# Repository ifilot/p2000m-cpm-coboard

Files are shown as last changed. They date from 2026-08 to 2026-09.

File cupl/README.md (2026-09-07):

# ATF1502AS CUPL source

This directory contains the first CPLD implementation for the
`pcb/modern-revised` schematic. It targets an ATF1502AS in a PLCC-44 socket
with JTAG left enabled.

## Implemented behavior

- Reset selects the normal factory P2000 memory map. In this mode P0-P7
  reproduce the original 82S123 table independently of `/MRQ`, and local
  SRAM stays disabled.
- A normal Z80 I/O write to `0x20-0x2F` latches D7 as the CP/M-map enable.
- The CP/M map is:

| CPU range | Selected target |
|---|---|
| `0x0000-0x3FFF` | Motherboard RAM (`P1/RAMS1`) |
| `0x4000-0x9FFF` | Expansion RAM (`P7/RAMS2`) |
| `0xA000-0xDFFF` | Local 16 KiB SRAM (`/RAMS3`) |
| `0xE000-0xEFFF` | Second 4 KiB cartridge slice (`P5/CARS1`) |
| `0xF000-0xFFFF` | Video window through translated expansion address `0x5xxx` |

- In CP/M mode, `RA15..RA12` is `A15..A12 + 6` modulo 16. In normal mode,
  the address passes through unchanged.
- J3/pin 44 is low for the P2000M and high for the P2000T. The T model also
  asserts `/VIDS` for `0xF000-0xF7FF`, matching its 2 KiB physical video RAM.
- In CP/M mode, `/MRQ` gates every memory selection. Local `/RAMS3` always
  requires both CP/M mode and an active memory cycle, so I/O cycles cannot
  enable the local SRAM.

The fixed pin assignment is in `p2000m-cpm-coboard.pld`. Any schematic pin
change must be reflected there and in `verify.py`.

## Separate stock-only diagnostic image

`p2000m-stock-prom.pld` is a combinational replacement for the original
`literature/82s123_dump_mobo.bin` PROM table. It has no mode register, port
decoder, reset dependency, or `/MRQ` gating. Local `/RAMS3` is permanently high.
RA12-RA15 always equal A12-A15; A0-A11 pass directly through the PCB from J1 to
J2, so the expansion/video board receives the original CPU address.

Build and verify it separately:

```bat
cupl\build.bat stock
```

```sh
./cupl/build.sh stock
python3 cupl/verify.py --stock
```

Program `p2000m-stock-prom.jed` for this test. The fit uses 13/32 logic cells,
zero flip-flops, and leaves JTAG enabled. Its build does not overwrite the
CP/M-capable image. This reproduces the PROM's logical table; propagation
delays and physical board connections still require a hardware test.

For a controlled output-slew comparison, `p2000m-stock-fast.pld` contains the
same stock logic, fitted with `-str output_fast ON`. Build with `build.bat stock-fast`
or `./cupl/build.sh stock-fast`; program `p2000m-stock-fast.jed`. Verify with
`python3 cupl/verify.py --stock --source cupl/p2000m-stock-fast.pld`.
Fast slew changes output transitions, not the chip's physical speed grade;
it may improve timing margin or worsen ringing depending on the wiring.

## Windows build

Install WinCUPL II and run:

```bat
cupl\build.bat
```

The scripts expect WinCUPL in `C:\WINCUPL`. Override that location when
needed:

```bat
set CUPL_ROOT=C:\path\to\WINCUPL
cupl\build.bat
```

## Linux build with Wine

Install WinCUPL into a Wine prefix and run:

```sh
./cupl/build.sh
```

By default the script uses `${WINEPREFIX:-$HOME/.wine}/drive_c/WINCUPL`.
An alternative installation can be selected with:

```sh
CUPL_ROOT=/path/to/WINCUPL ./cupl/build.sh
```

Both build wrappers perform the same two proprietary steps:

1. `cupl.exe` compiles the CUPL source to a `.tt2` netlist.
2. `find1502.exe` fits that netlist for `P1502C44` and emits the `.jed` file.

The fitter is invoked with `JTAG ON`. Review the generated `.fit` and `.pin`
reports before programming hardware.

## Verification

The behavioral checker requires only Python 3:

```sh
python3 cupl/verify.py
python3 cupl/verify.py --dump
```

It parses and evaluates the actual `.pld` equations against independent expected
memory tables. Checks cover source pins and device, all 256 combinations of
2 KiB block/map/model/memory-request level, all sixteen address translations,
and 16,384 port/control/data/reset/prior-state combinations. Register checks
cover rising-edge capture, holding without an edge, asynchronous reset priority,
and complete write/reset sequences. `--dump` prints source-evaluated results.
Unsupported syntax, undefined signals, duplicate declarations, and combinational
feedback fail verification. Checks remain enabled under `python3 -O`.
Dependencies on inputs outside the corresponding truth-table sweep also fail,
so a newly introduced input cannot silently escape verification.

Run the checker regression tests, including deliberately broken CUPL equations:

```sh
python3 -m unittest discover -s cupl -p 'test_*.py'
```

This is functional source verification for the scalar CUPL syntax used here.
It does not verify JEDEC fuses, propagation delays, setup/hold timing, or physical
hardware. A fresh compiler/fitter run and review of its reports are still required.
The existing ATF1502AS fitter report uses 14 of 32 logic cells, with JTAG enabled.

Generated compiler and fitter files are ignored. Clean them with
`cupl\clean.bat` or `./cupl/clean.sh`.

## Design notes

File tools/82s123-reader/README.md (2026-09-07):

# 82S123 ROM Reader

Hardware and software to read out 82S123 bipolar PROM chips using an
[Arduino Leonardo](https://docs.arduino.cc/hardware/leonardo)-based shield,
plus a Qt6 desktop GUI to drive it.

The repository is organized as follows:

* [arduino/82s123-reader](arduino/82s123-reader) — firmware for the Leonardo.
  It exposes a small serial command protocol (handshake + checksummed read)
  so a host application can request a dump on demand, rather than the board
  dumping blindly on boot.
* [gui](gui) — a Qt6 Widgets desktop application that connects to the board,
  reads the 32 bytes of the chip, displays them (hex / decimal / binary /
  ASCII), and exports the dump as `.bin`, Intel `.hex`, or a text table. See
  [gui/README.md](gui/README.md) for build and usage instructions.
* [kicad/82s123-reader](kicad/82s123-reader) — KiCad project for the reader
  shield.

## Wiring

| Signal | Arduino pin |
|---|---|
| ROM A0–A4 | D2, D3, D4, D5, D6 |
| ROM /CE | D7 |
| ROM D0–D3 | A3–A0 (PF4–PF7) |
| ROM D4–D7 | D8–D11 (PB4–PB7) |

## Firmware protocol

115200 baud, 8N1, ASCII, newline-terminated commands/responses:

| Host sends | Device replies |
|---|---|
| `PING` | `PONG 82S123-READER v0.1.0` |
| `READ` | 32× `AA:DD` lines (address:data, hex), then `CHK:xx` (XOR checksum of all 32 data bytes), then `OK` |
| anything else | `ERR UNKNOWN_CMD <cmd>` |

The GUI (or any other host, e.g. a serial terminal) drives the board with
these commands; the board never dumps unsolicited data, which makes reads
deterministic and easy to verify (missing bytes or a checksum mismatch are
detected instead of silently producing a bad dump).

## Quick start

1. Flash [`arduino/82s123-reader/82s123-reader.ino`](arduino/82s123-reader/82s123-reader.ino)
   to the Leonardo via the Arduino IDE.
2. Build the GUI — see [gui/README.md](gui/README.md).
3. Insert the 82S123 chip, connect the board, launch the GUI, connect to its
   serial port, and click **Read ROM**.

## Example dump

A sample 32-byte read from a 82S123 chip, as reported by the reader:

```
Address | Data
--------+------
0x00    | 0x02
0x01    | 0x07
0x02    | 0x0B
0x03    | 0x0F
0x04    | 0x12
0x05    | 0x17
0x06    | 0x1B
0x07    | 0x1F
0x08    | 0x22
0x09    | 0x27
0x0A    | 0x2A
0x0B    | 0x2F
0x0C    | 0x32
0x0D    | 0x37
0x0E    | 0x39
0x0F    | 0x3F
0x10    | 0x02
0x11    | 0x07
0x12    | 0x0B
0x13    | 0x0F
0x14    | 0x12
0x15    | 0x17
0x16    | 0x1B
0x17    | 0x1F
0x18    | 0x22
0x19    | 0x27
0x1A    | 0x2A
0x1B    | 0x2F
0x1C    | 0x32
0x1D    | 0x37
0x1E    | 0x3B
0x1F    | 0x3F
```

Read twice in a row, the dump was consistent except for address `0x0E`,
which alternated between `0x39` and `0x3B` — a sign of a marginal/floating
bit on that ROM read at the time (loose socket contact or a chip near its
switching threshold), rather than a firmware issue. The GUI's per-read
checksum check will flag such inconsistencies if they cause a corrupted
transfer, but a genuinely flaky chip/socket read that completes cleanly on
both ends can still produce different (self-consistent) data — worth
re-seating the chip and re-reading if you see this.

## Licensing

* All source code, i.e. the [firmware](arduino/82s123-reader) and the
  [GUI](gui), is released under a
  [GPLv3 license](https://www.gnu.org/licenses/gpl-3.0.html).
* The hardware files to (re)produce the Arduino shield are released under
  the [CC BY-SA 4.0](https://creativecommons.org/licenses/by-sa/4.0/)
  license.

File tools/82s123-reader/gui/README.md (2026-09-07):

# 82S123 ROM Reader — Qt6 GUI

A minimal Qt6 Widgets front-end for the Arduino Leonardo based 82S123 PROM
reader. It talks to the board over a small, checksummed serial protocol
(see [Protocol](#protocol) below), reads all 32 bytes of the chip, shows
them in a table (hex / decimal / binary / ASCII), and exports the dump as
`.bin`, Intel `.hex`, or a plain-text table. It can also flash the board
with the exact firmware it was built against (see
[Flashing firmware](#flashing-firmware)).

The UI intentionally uses only stock Qt widgets and the platform's default
style — no custom stylesheets/CSS.

## Layout

```
gui/
  CMakeLists.txt
  src/
    main.cpp                entry point
    mainwindow.h/.cpp        Qt Widgets UI
    romreader.h/.cpp         QSerialPort-based protocol client
    firmwareflasher.h/.cpp   compiles/uploads the firmware via arduino-cli
    firmware_source.h.in     template into which the .ino is embedded
  resources/
    app.svg                  icon source
    app.ico                  Windows executable icon (generated from app.svg)
    icons/app-*.png          in-app icon (generated from app.svg)
    app.qrc                  Qt resource bundling the PNGs
    app.rc.in                Windows resource script embedding app.ico
```

The firmware sketch (`arduino/82s123-reader/82s123-reader.ino`) is embedded
into the binary at CMake configure time as a generated header
(`build/generated/firmware_source.h`), so the "Flash Firmware" feature
always uploads the exact sketch version the GUI was built against —
editing the `.ino` and reconfiguring picks up the change automatically.

The app icon is embedded twice, both generated from the single
`resources/app.svg` source (regenerate with `rsvg-convert` + ImageMagick's
`convert` if you edit the SVG — there's no build-time step for this, unlike
the firmware): as PNGs via `app.qrc` for the in-app window/taskbar icon, and
as `app.ico` baked into the `.exe`'s own PE resources on Windows (via a
generated `.rc` file), so it shows up in Explorer and the taskbar even
before the app runs.

## Building

Requires Qt6 (`Widgets` + `SerialPort` modules) and CMake ≥ 3.16.

### Windows via MSYS2 (UCRT64)

Install the needed packages once from an MSYS2 shell:

```
pacman -S mingw-w64-ucrt-x86_64-qt6-base mingw-w64-ucrt-x86_64-qt6-serialport \
          mingw-w64-ucrt-x86_64-cmake mingw-w64-ucrt-x86_64-ninja \
          mingw-w64-ucrt-x86_64-toolchain
```

Then, from a **UCRT64** MSYS2 shell (or any shell with `C:\msys64\ucrt64\bin`
on `PATH`):

```
cmake -G Ninja -S gui -B gui/build -DCMAKE_PREFIX_PATH=C:/msys64/ucrt64 -DCMAKE_BUILD_TYPE=Release
cmake --build gui/build
```

The resulting `prom82s123-reader.exe` dynamically links `Qt6Core`, `Qt6Gui`,
`Qt6Widgets`, `Qt6SerialPort`, plus the MinGW runtime
(`libgcc_s_seh-1.dll`, `libstdc++-6.dll`, `libwinpthread-1.dll`). To make the
build folder self-contained/redistributable:

```
cd gui/build
windeployqt6.exe prom82s123-reader.exe --no-translations --no-opengl-sw
cp C:/msys64/ucrt64/bin/{libgcc_s_seh-1,libstdc++-6,libwinpthread-1}.dll .
```

### Linux

```
sudo apt install qt6-base-dev qt6-serialport-dev cmake ninja-build
cmake -G Ninja -S gui -B gui/build
cmake --build gui/build
```

On Linux, add your user to the `dialout` group (or equivalent) to get
permission to open `/dev/ttyACM*`.

## Usage

1. Flash the firmware onto the Leonardo — either with the Arduino IDE, or
   with the GUI itself (see below).
2. Launch `prom82s123-reader`, pick the board's serial port, click **Connect**
   (the app performs a `PING`/`PONG` handshake and will report a clear error
   if the board doesn't answer).
3. Click **Read ROM** to pull all 32 bytes; the table fills in and the
   checksum is verified automatically.
4. **Save As…** to export as `.bin`, Intel `.hex`, or a text table.
5. **View → Show Log** for a raw transcript of the serial conversation,
   useful for troubleshooting.

## Flashing firmware

The **Flash Firmware…** button (also under the **Firmware** menu) compiles
and uploads the embedded sketch directly from the GUI, by shelling out to
[`arduino-cli`](https://arduino.github.io/arduino-cli/) — it does not bundle
its own AVR toolchain.

* On first use, the app searches `PATH` and a couple of well-known install
  locations for `arduino-cli`; if it can't find one, it prompts you to
  browse to the executable. The chosen path is remembered (`QSettings`) and
  can be changed any time via **Firmware → Locate arduino-cli…**.
* The `arduino:avr` core must be installed once: `arduino-cli core install
  arduino:avr`.
* Flashing closes any active connection to the board first (the port can't
  be shared between the GUI and the upload tool), asks for confirmation
  (it overwrites the board's firmware), then streams `arduino-cli`'s
  compile/upload output live into the log panel while an indeterminate
  progress dialog is shown (cancellable).
* Internally it writes the embedded sketch to a temporary directory and
  runs `arduino-cli compile --upload -p <port> --fqbn arduino:avr:leonardo
  <sketch>` — the same command you'd run by hand.

## Protocol

115200 baud, 8N1, ASCII, newline-terminated commands/responses:

| Host sends | Device replies |
|---|---|
| `PING` | `PONG 82S123-READER v0.1.0` |
| `READ` | 32× `AA:DD` lines (address:data, hex), then `CHK:xx` (XOR checksum of all data bytes), then `OK` |
| anything else | `ERR UNKNOWN_CMD <cmd>` |

The GUI treats the handshake and the read as timeout-guarded operations
(1.5 s / 3 s respectively) and validates that all 32 addresses were seen and
that the checksum matches before accepting a read, so a dropped byte or a
disconnected cable is reported instead of silently producing a bad dump.

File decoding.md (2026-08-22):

# P2000M CP/M memory-map audit

Sources checked:

- `literature/MW106 CPM Kaart.pdf`, especially page 3 (EPROM bytes) and page
  16 (SANECAL schematic).
- `literature/P2000MT Field Support Manual.pdf`, especially pages 3-3, 3-5,
  3-14, 3-18 and 3-19.
- `software/CPM Nater.bin`.
- The current KiCad schematic and routed PCB.

## Result

The authoritative CP/M map is:

| CPU range | Effective device |
|---|---|
| `0x0000-0x3FFF` | 16 KiB motherboard RAM |
| `0x4000-0x9FFF` | 24 KiB expansion-card RAM |
| `0xA000-0xDFFF` | 16 KiB local card RAM |
| `0xE000-0xEFFF` | Second 4 KiB cartridge-ROM slice |
| `0xF000-0xFFFF` | P2000M video RAM |

The monitor ROM is not mapped in CP/M mode. The machine-readable source of
truth is `P2000M_MEMORY_TABLE` in `scripts/build_eeprom.py`.

## Original maps

The stock functional map documented by Philips is:

| CPU range | Device |
|---|---|
| `0x0000-0x0FFF` | Monitor ROM |
| `0x1000-0x4FFF` | Cartridge ROM |
| `0x5000-0x5FFF` | P2000M video RAM |
| `0x6000-0x9FFF` | 16 KiB motherboard RAM |
| `0xA000-0xFFFF` | Up to 24 KiB expansion RAM |

MW106 page 3 prints these 32 bytes for its M-model CP/M table:

```text
7E 7E 7E 7E  FE FE FE FE  7D 7D 7D 7D  7D 7D 7D 7D
FD FD FD FD  F9 F9 F9 F9  F9 F9 F9 F9  DC DC FD FD
```

One byte covers a 2 KiB CPU page. Together with the SANECAL local RAM and its
address adder, the effective M-model CP/M map is:

| CPU range | MW106 byte | Effective device |
|---|---:|---|
| `0x0000-0x1FFF` | `0x7E` | Motherboard RAM |
| `0x2000-0x3FFF` | `0xFE` | Motherboard RAM (with the literal extra `RAMS2` output) |
| `0x4000-0x7FFF` | `0x7D` | SANECAL local 16 KiB RAM; all external selects are off |
| `0x8000-0x9FFF` | `0xFD` | Expansion RAM |
| `0xA000-0xDFFF` | `0xF9` | Expansion RAM |
| `0xE000-0xEFFF` | `0xDC` | CP/M cartridge boot ROM |
| `0xF000-0xFFFF` | `0xFD` | P2000M video RAM |

## Revised-board decode

### U2 address inputs

| U2 input | Source |
|---|---|
| A0-A4 | CPU A11-A15 |
| A5 | J3: M=`0`, T=`1` |
| A6 | `/MRQ` |
| A7-A16 | GND |

Therefore:

```text
U2 address = (CPU address >> 11) | (T_model << 5) | (/MRQ_level << 6)
```

The additional `/MRQ` input is handled correctly. Memory cycles use U2
addresses `0x00-0x3F`. I/O and idle cycles use `0x40-0x7F`, which must contain
`0x7D` throughout so U1 cannot be selected while `/RD` or `/WR` is active for
I/O.

### U2 outputs as actually routed

| Bit | Net | Active level |
|---:|---|---:|
| D0 | P0 `/MBEN` | 0 |
| D1 | P1 `RAMS1` | 1 |
| D2 | `/RAMS3` (U1 `/CS`) | 0 |
| D3 | P2 `/VIDS` | 0 |
| D4 | Not connected | - |
| D5 | P5 `/CARS1` | 0 |
| D6 | P6 `/CARS2` | 0 |
| D7 | P7 `RAMS2` | 1 |

P3 `/ROMS1` and P4 `/ROMS2` are held inactive by R2 and R1. Because D4 is not
connected, an EEPROM option that tries to select ROM2 through D4 cannot work on
this PCB.

### Authoritative P2000M CP/M table

| CPU range | U2 byte | Effective device |
|---|---:|---|
| `0x0000-0x3FFF` | `0x7E` | 16 KiB motherboard RAM |
| `0x4000-0x9FFF` | `0xFD` | 24 KiB expansion-card RAM |
| `0xA000-0xDFFF` | `0x79` | 16 KiB U1 SRAM |
| `0xE000-0xEFFF` | `0x5C` | 4 KiB CP/M cartridge boot-ROM slice |
| `0xF000-0xFFFF` | `0xFD` | P2000M video RAM |

U1 uses CPU A0-A13 directly and has A14 grounded. Its four physical 4 KiB
blocks appear linearly from `0x0000` through `0x3FFF` within the logical
`0xA000-0xDFFF` window. Every SRAM byte is mapped exactly once.

The CP/M boot ROM contains `LD A,0x80` at file offset `0x036D` and
`OUT (0x20),A` at `0x0372`. U5 correctly decodes the mirrored write-port range `0x20-0x2F`, and
U4 therefore must (and does) latch D7, despite the D0 annotation in the MW106
drawing.

## EEPROM image

The concise generator is `scripts/build_eeprom.py`:

```sh
python3 scripts/build_eeprom.py p2000m-cpm-eeprom.bin
```

It writes a complete 128 KiB SST39SF010 image. Bytes `0x00-0x3F` are the M/T
memory-cycle tables, bytes `0x40-0x7F` are the `/MRQ=1` all-off tables, and the
unaddressed remainder is erased (`0xFF`).

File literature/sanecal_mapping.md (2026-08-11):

# SANECAL MW106 M-model mapping

PROM encoding as printed in MW106:

```text
00  7E 7E 7E 7E  FE FE FE FE  7D 7D 7D 7D  7D 7D 7D 7D
10  FD FD FD FD  F9 F9 F9 F9  F9 F9 F9 F9  DC DC FD FD
```

Several printed values cannot form a valid decode with the signal assignments
on this board. `FE` asserts both active-high RAM selects, `7D` selects no
memory, `F9` asserts both `RAMS2` and `RAMS3/`, and `DC` asserts both `RAMS2`
and `CARS1/`. They are treated here as errors in the printed MW106 table. The
corrected functional encoding keeps the memory selects mutually exclusive:

```text
00  7E 7E 7E 7E  7E 7E 7E 7E  FD FD FD FD  FD FD FD FD
10  FD FD FD FD  79 79 79 79  79 79 79 79  5C 5C FD FD
```

## Signal lines

| Line | Signal on this board | Active level | Function |
|---|---|---:|---|
| D0 | `MBEN/` | 0 | Enables the memory data-bus path |
| D1 | `RAMS1` | 1 | Selects the 16 KiB motherboard system RAM |
| D2 | `RAMS3/` | 0 | Selects the CP/M board's local RAM |
| D3 | `VIDS/` | 0 | Selects video RAM |
| D4 | Unconnected | - | No function on this board |
| D5 | `CARS1/` | 0 | Selects cartridge ROM bank 1 (`1000-2FFF`) |
| D6 | `CARS2/` | 0 | Selects cartridge ROM bank 2 (`3000-4FFF`) |
| D7 | `RAMS2` | 1 | Selects the 24 KiB expansion RAM |
| P3 | `ROMS1/` | 0 | Selects the lower 2 KiB monitor ROM; held at 1 (inactive) on this board |
| P4 | `ROMS2/` | 0 | Selects the upper 2 KiB monitor ROM; held at 1 (inactive) on this board |

## Interpretation

Each PROM address covers one 2 KiB CPU-address block because CPU address lines
A11-A15 drive the PROM address inputs. Consecutive blocks that contain the same
data are combined below; the block count states how many 2 KiB blocks the row
covers. `0` is low and `1` is high, and the slash in a signal name denotes an
active-low signal. D4 is included even though it is not connected. P3 and P4
are not driven by the PROM and remain high throughout.

The final column relates the CP/M-visible range to the corresponding part of
the stock P2000M map. `RAMS3/` has no equivalent destination in the stock map;
when asserted, it connects the CPU to the RAM fitted on the CP/M board.

| Data | Blocks | PROM addresses | CPU address range | D7 `RAMS2` | D6 `CARS2/` | D5 `CARS1/` | D4 unconnected | D3 `VIDS/` | D2 `RAMS3/` | D1 `RAMS1` | D0 `MBEN/` | P3 `ROMS1/` | P4 `ROMS2/` | Landing relative to the stock P2000M map |
|---:|---:|---:|---|---:|---:|---:|---:|---:|---:|---:|---:|---:|---:|---|
| `7E` | 8 | `00-07` | `0000-3FFF` | 0 | 1 | 1 | 1 | 1 | 1 | 1 | 0 | 1 | 1 | `6000-9FFF`: all 16 KiB of motherboard RAM |
| `FD` | 12 | `08-13` | `4000-9FFF` | 1 | 1 | 1 | 1 | 1 | 1 | 0 | 1 | 1 | 1 | `A000-FFFF`: all 24 KiB of expansion RAM |
| `79` | 8 | `14-1B` | `A000-DFFF` | 0 | 1 | 1 | 1 | 1 | 0 | 0 | 1 | 1 | 1 | `RAMS3/` connects to the 16 KiB RAM on the CP/M board; there is no stock-map equivalent |
| `5C` | 2 | `1C-1D` | `E000-EFFF` | 0 | 1 | 0 | 1 | 1 | 1 | 0 | 0 | 1 | 1 | Selects the `CARS1/` ROM slice originally visible at `2000-2FFF` |
| `FD` | 2 | `1E-1F` | `F000-FFFF` | 1 | 1 | 1 | 1 | 1 | 1 | 0 | 1 | 1 | 1 | `5000-5FFF`: M-model video RAM through the translated address and the video-board decoder |

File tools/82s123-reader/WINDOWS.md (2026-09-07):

# Windows reader control

Software copied from `D:\PROGRAMMING\KiCAD\82S123-reader`, commit
`a315694` (Arduino firmware, Qt GUI and original README; hardware and build
outputs excluded). Original licensing remains as described in README.md.

The local firmware identifies as `82S123-READER v0.1.1` to distinguish this
copy. Its reading logic includes the existing Leonardo JTAG-disable sequence.
The GUI binary-export bug is corrected here: `.bin` files use binary mode.

Use Windows PowerShell and the Windows Arduino CLI:

```powershell
.\tools\82s123-reader\windows.ps1 -Action Build
.\tools\82s123-reader\windows.ps1 -Action Ports
.\tools\82s123-reader\windows.ps1 -Action Flash -Port COM5
.\tools\82s123-reader\windows.ps1 -Action Read -Port COM5 -Reads 3
```

Replace COM5 with the actual Leonardo port. Close the GUI/Serial Monitor
before using this controller. `Build` does not upload anything. `Flash`
recompiles and uploads with verification; it requires an explicit port.
`Read` checks the firmware identity, captures three independent reads, checks
each transfer checksum, compares all reads, and compares against the existing
`literature/82s123_dump_mobo.bin`. It never overwrites that reference file.

Captures are written as exact binary bytes alongside a serial log in an
ignored, timestamped `captures` subdirectory. Repeated agreement and the
checksum do not prove that the electrical reading of the PROM is correct.

From WSL, invoke the script through `powershell.exe -NoProfile
-ExecutionPolicy Bypass -File` using its Windows path. Compilation, uploading
and serial access all run on Windows; no WSL USB forwarding is needed.

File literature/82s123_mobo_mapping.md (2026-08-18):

# 82S123 motherboard PROM — normal (factory) mapping

Source: `literature/82s123_dump_mobo.bin`, a 32-byte dump of the 82S123 PROM
fitted on the motherboard, before any CP/M-board modification.

PROM contents as dumped:

```text
00  74 74 5C 5C  5C 5C 3C 3C  3C 3C 79 7D  7E 7E 7E 7E
10  7E 7E 7E 7E  FD FD FD FD  FD FD FD FD  FD FD FD FD
```

This is a clean decode: every byte selects at most one device, and no output
combination is contradictory (unlike the printed MW106 CP/M table, see
[sanecal_mapping.md](sanecal_mapping.md)). It is byte-for-byte identical to
the "P2000M, 1×2732" table in `literature/address_decoding.txt`, which fixes
both the ROM configuration (one 4 KiB 2732, not two 2 KiB 2716s — bytes
`00-01` are both `74`, not `74`/`6C`) and the signal-to-bit wiring below. This
dump is also the empirical source for that table's `5000-5FFF` row, which was
previously an unverified guess (see the note below).

## Signal lines

| Line | Signal | Active level | Function |
|---|---|---:|---|
| D0 | `MBEN/` | 0 | Enables the memory data-bus path |
| D1 | `RAMS1` | 1 | Selects the 16 KiB motherboard system RAM |
| D2 | `VIDS/` | 0 | Selects video RAM |
| D3 | `ROMS1/` | 0 | Selects the monitor ROM (2732: whole 4 KiB device) |
| D4 | `ROMS2/` | 0 | Selects the upper monitor-ROM half (unused with a 2732; only relevant for the 2×2716 variant) |
| D5 | `CARS1/` | 0 | Selects cartridge ROM bank 1 (`1000-2FFF`) |
| D6 | `CARS2/` | 0 | Selects cartridge ROM bank 2 (`3000-4FFF`) |
| D7 | `RAMS2` | 1 | Selects the 24 KiB expansion RAM |

## Interpretation

Each PROM address covers one 2 KiB CPU-address block because CPU address lines
A11-A15 drive the PROM address inputs. Consecutive blocks that contain the
same data are combined below.

| Data | Blocks | PROM addresses | CPU address range | D7 `RAMS2` | D6 `CARS2/` | D5 `CARS1/` | D4 `ROMS2/` | D3 `ROMS1/` | D2 `VIDS/` | D1 `RAMS1` | D0 `MBEN/` | Function |
|---:|---:|---:|---|---:|---:|---:|---:|---:|---:|---:|---:|---|
| `74` | 2 | `00-01` | `0000-0FFF` | 0 | 1 | 1 | 1 | 0 | 1 | 0 | 0 | 4 KiB monitor ROM (single 2732) |
| `5C` | 4 | `02-05` | `1000-2FFF` | 0 | 1 | 0 | 1 | 1 | 1 | 0 | 0 | Cartridge ROM bank 1 |
| `3C` | 4 | `06-09` | `3000-4FFF` | 0 | 0 | 1 | 1 | 1 | 1 | 0 | 0 | Cartridge ROM bank 2 |
| `79` | 1 | `0A` | `5000-57FF` | 0 | 1 | 1 | 1 | 1 | 0 | 0 | 1 | Video RAM |
| `7D` | 1 | `0B` | `5800-5FFF` | 0 | 1 | 1 | 1 | 1 | 1 | 0 | 1 | Nothing selected (unused window) |
| `7E` | 8 | `0C-13` | `6000-9FFF` | 0 | 1 | 1 | 1 | 1 | 1 | 1 | 0 | 16 KiB motherboard RAM |
| `FD` | 12 | `14-1F` | `A000-FFFF` | 1 | 1 | 1 | 1 | 1 | 1 | 0 | 1 | 24 KiB expansion RAM |

## Note on M vs T

This chip was pulled from a known P2000M motherboard, so the `79`/`7D` split
at `5000-5FFF` (`VIDS/` asserted for `5000-57FF`, nothing selected for
`5800-5FFF`) is confirmed M-model data.

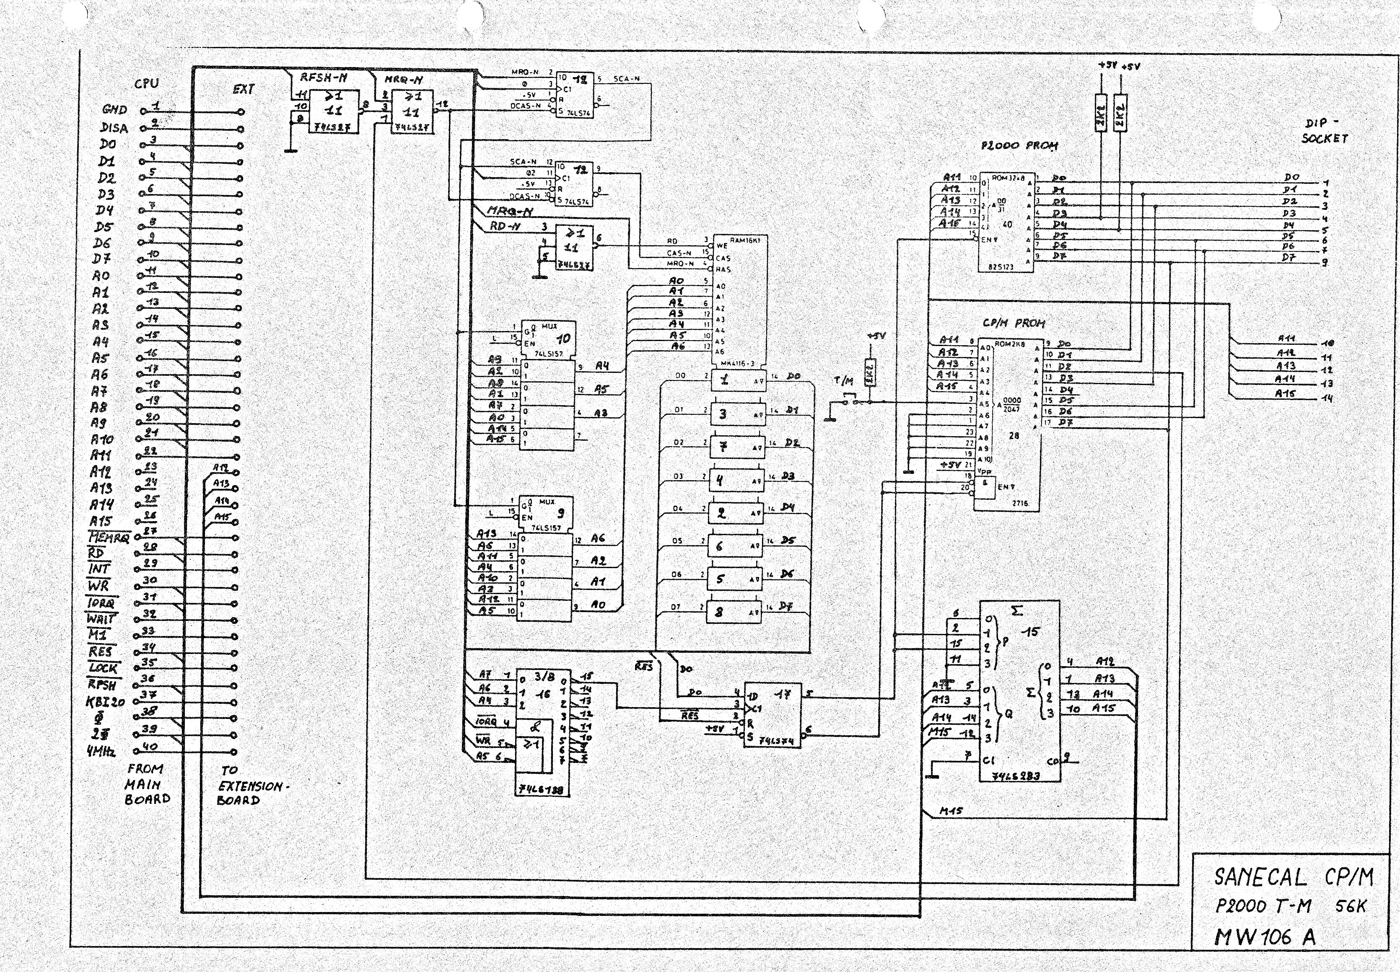
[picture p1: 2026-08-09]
literature/MW106-CPM-board-page16-restored-scan.png

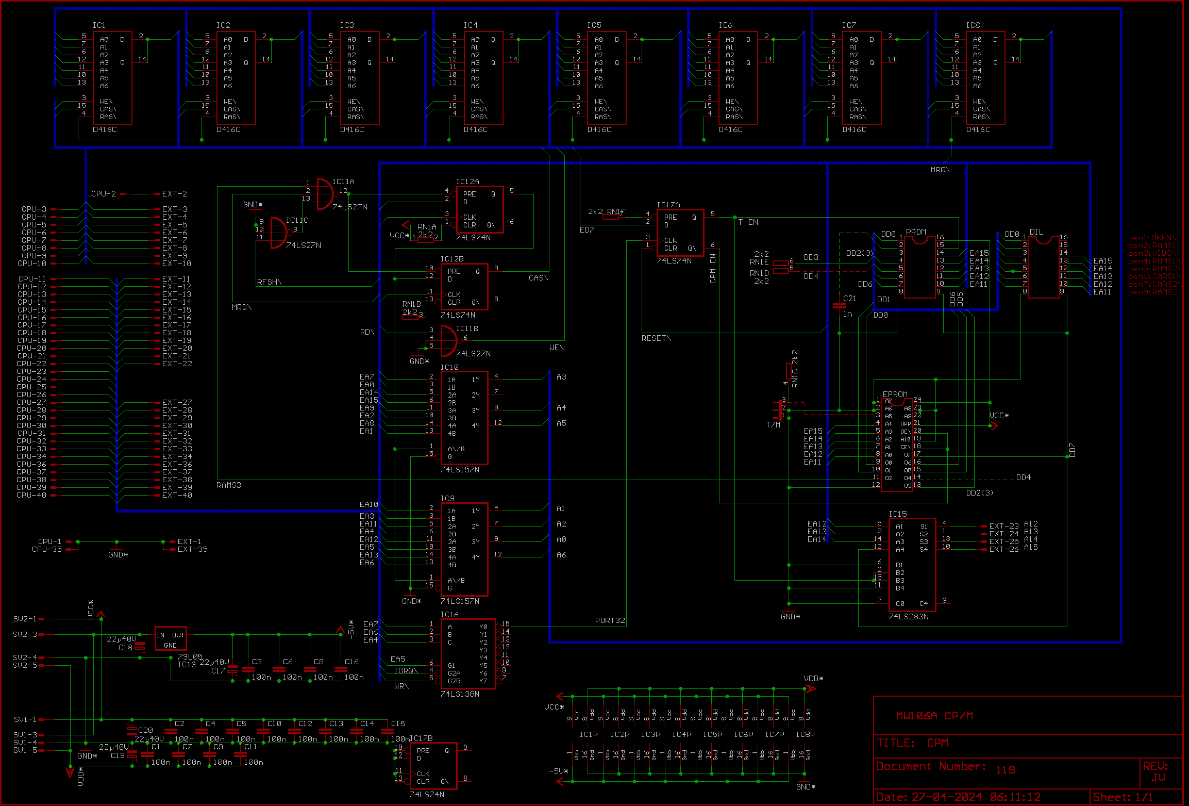
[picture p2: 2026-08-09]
literature/CPM.png.832bb497661575f88c8b2b641b03f00d.png

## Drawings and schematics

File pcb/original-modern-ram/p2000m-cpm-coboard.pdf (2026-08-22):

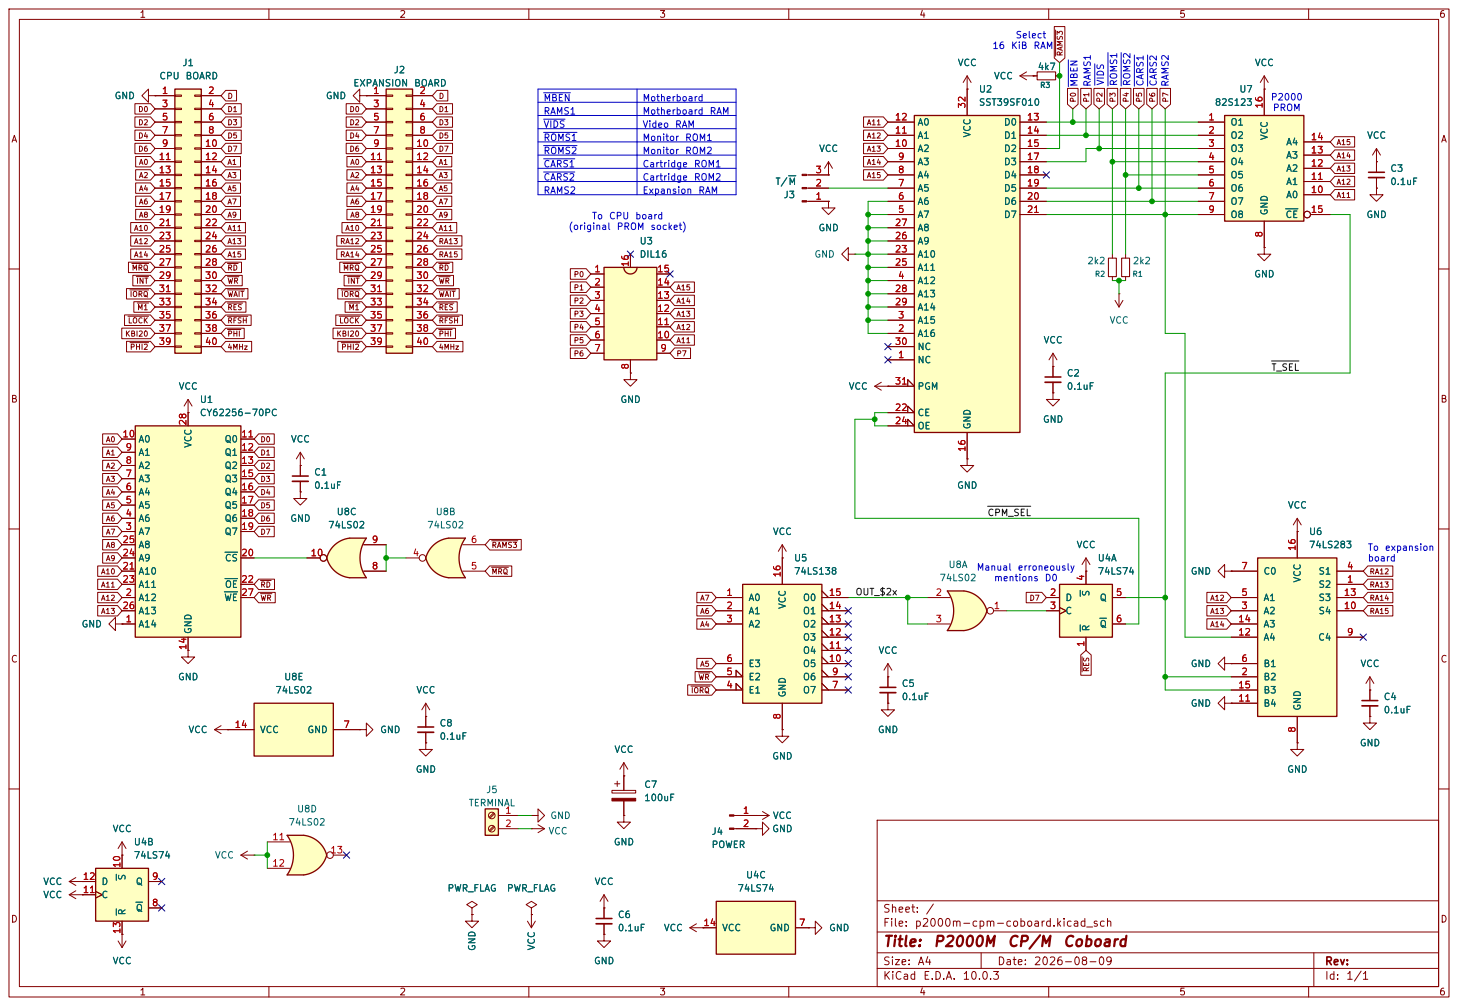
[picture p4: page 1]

A12 P0 RAMS3
GND GND 16 VCC 32 NC 1

Size: A4 | Rev:
KiCad E.D.A. 10.0.3 | Id: 1/1

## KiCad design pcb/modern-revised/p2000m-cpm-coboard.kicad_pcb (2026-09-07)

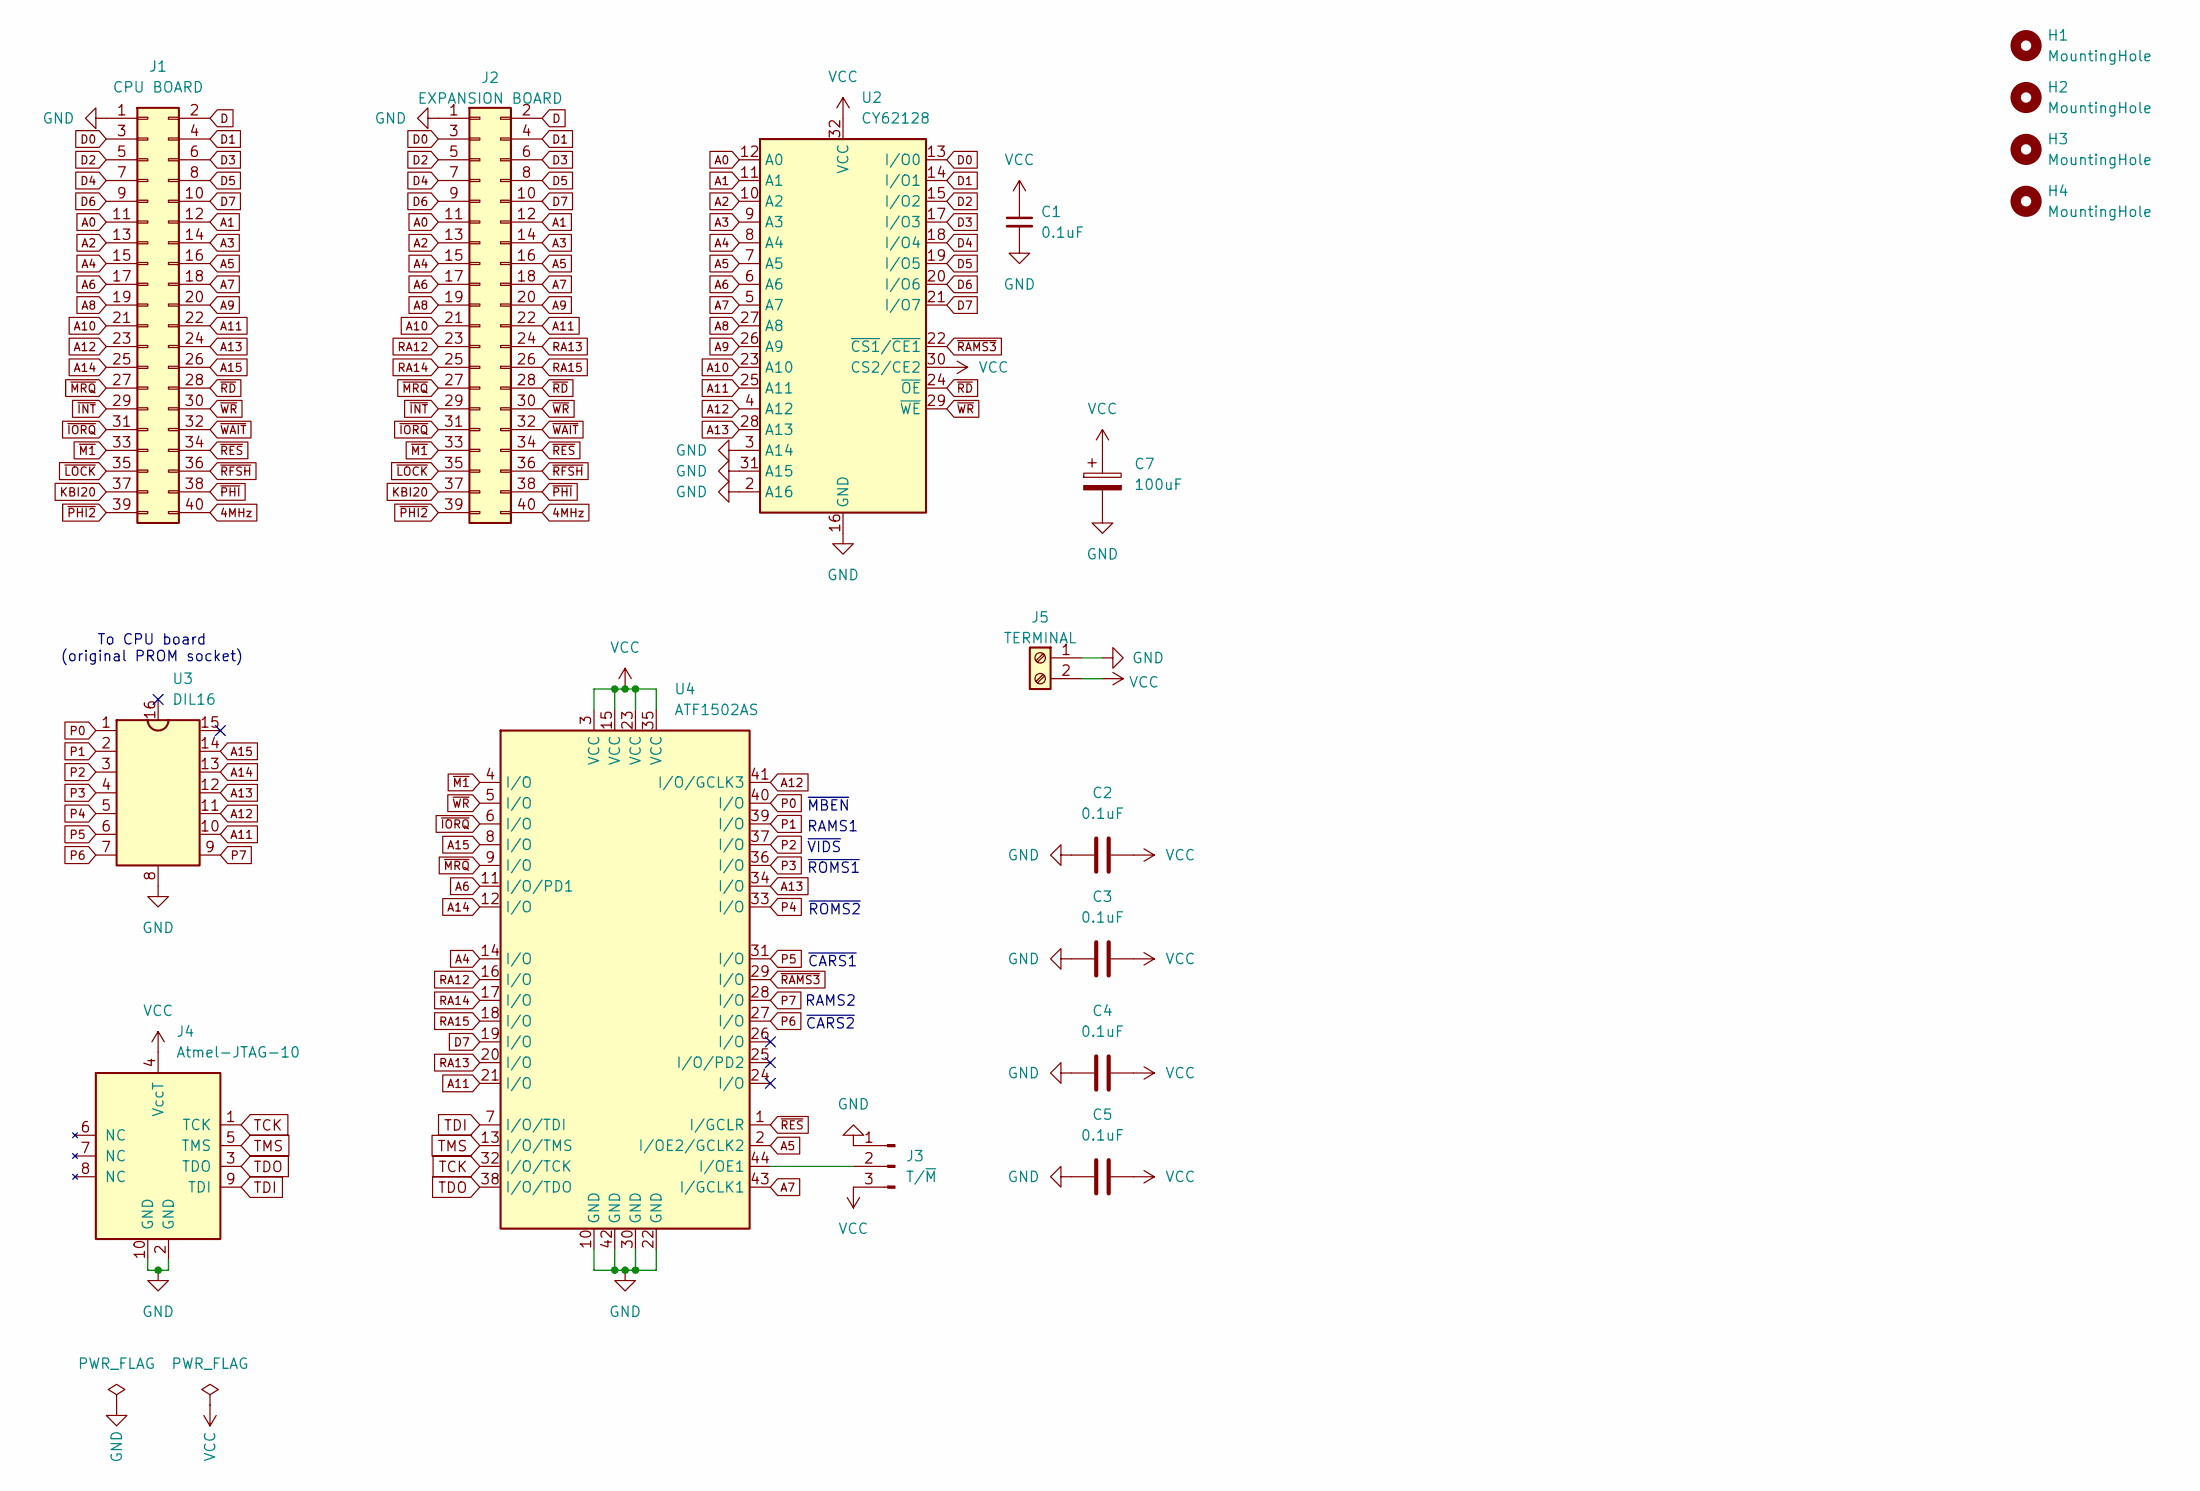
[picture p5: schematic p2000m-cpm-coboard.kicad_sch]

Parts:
C1, C2, C3, C4, C5: 0.1uF; C_0805_2012Metric_Pad1.18x1.45mm_HandSolder
C7: 100uF; CP_Radial_D6.3mm_P2.50mm
H1, H2, H3, H4: MountingHole; MountingHole_3.2mm_M3_Pad_Via
J1: CPU BOARD; IDC-Header_2x20_P2.54mm_Vertical
J2: EXPANSION BOARD; IDC-Header_2x20_P2.54mm_Vertical
J3: T/~{M}; PinHeader_1x03_P2.54mm_Vertical
J4: Atmel-JTAG-10; IDC-Header_2x05_P2.54mm_Vertical
J5: TERMINAL; TerminalBlock_RND_205-00232_1x02_P5.08mm_Horizontal
U2: CY62128; SOP-32_11.305x20.495mm_P1.27mm
U3: DIL16; DIP-16_W7.62mm_Socket
U4: ATF1502AS; PLCC-44_THT-Socket

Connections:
4MHz: J1.40, J2.40
A0: J1.11, J2.11, U2.12 (A0)
A1: J1.12, J2.12, U2.11 (A1)
A2: J1.13, J2.13, U2.10 (A2)
A3: J1.14, J2.14, U2.9 (A3)
A4: J1.15, J2.15, U2.8 (A4), U4.14 (I/O)
A5: J1.16, J2.16, U2.7 (A5), U4.2 (I/OE2/GCLK2)
A6: J1.17, J2.17, U2.6 (A6), U4.11 (I/O/PD1)
A7: J1.18, J2.18, U2.5 (A7), U4.43 (I/GCLK1)
A8: J1.19, J2.19, U2.27 (A8)
A9: J1.20, J2.20, U2.26 (A9)
A10: J1.21, J2.21, U2.23 (A10)
A11: J1.22, J2.22, U2.25 (A11), U3.10, U4.21 (I/O)
A12: J1.23, U2.4 (A12), U3.11, U4.41 (I/O/GCLK3)
A13: J1.24, U2.28 (A13), U3.12, U4.34 (I/O)
A14: J1.25, U3.13, U4.12 (I/O)
A15: J1.26, U3.14, U4.8 (I/O)
D: J1.2, J2.2
D0: J1.3, J2.3, U2.13 (I/O0)
D1: J1.4, J2.4, U2.14 (I/O1)
D2: J1.5, J2.5, U2.15 (I/O2)
D3: J1.6, J2.6, U2.17 (I/O3)
D4: J1.7, J2.7, U2.18 (I/O4)
D5: J1.8, J2.8, U2.19 (I/O5)
D6: J1.9, J2.9, U2.20 (I/O6)
D7: J1.10, J2.10, U2.21 (I/O7), U4.19 (I/O)
GND: C1.2, C2.2, C3.2, C4.2, C5.2, C7.2, J1.1, J2.1, J3.1, J4.2 (GND), J4.10 (GND), J5.1, U2.2 (A16), U2.3 (A14), U2.16 (GND), U2.31 (A15), U3.8, U4.10 (GND), U4.22 (GND), U4.30 (GND), U4.42 (GND)
KBI20: J1.37, J2.37
unnamed: J3.2, U4.44 (I/OE1)
P0: U3.1, U4.40 (I/O)
P1: U3.2, U4.39 (I/O)
P2: U3.3, U4.37 (I/O)
P3: U3.4, U4.36 (I/O)
P4: U3.5, U4.33 (I/O)
P5: U3.6, U4.31 (I/O)
P6: U3.7, U4.27 (I/O)
P7: U3.9, U4.28 (I/O)
RA12: J2.23, U4.16 (I/O)
RA13: J2.24, U4.20 (I/O)
RA14: J2.25, U4.17 (I/O)
RA15: J2.26, U4.18 (I/O)
TCK: J4.1 (TCK), U4.32 (I/O/TCK)
TDI: J4.9 (TDI), U4.7 (I/O/TDI)
TDO: J4.3 (TDO), U4.38 (I/O/TDO)
TMS: J4.5 (TMS), U4.13 (I/O/TMS)
VCC: C1.1, C2.1, C3.1, C4.1, C5.1, C7.1, J3.3, J4.4 (VccT), J5.2, U2.30 (CS2/CE2), U2.32 (VCC), U4.3 (VCC), U4.15 (VCC), U4.23 (VCC), U4.35 (VCC)
~INT: J1.29, J2.29
~IORQ: J1.31, J2.31, U4.6 (I/O)
~LOCK: J1.35, J2.35
~M1: J1.33, J2.33, U4.4 (I/O)
~MRQ: J1.27, J2.27, U4.9 (I/O)
~PHI2: J1.39, J2.39
~PHI: J1.38, J2.38
~RAMS3: U2.22 (~CS1/~CE1), U4.29 (I/O)
~RD: J1.28, J2.28, U2.24 (~OE)
~RES: J1.34, J2.34, U4.1 (I/GCLR)
~RFSH: J1.36, J2.36
~WAIT: J1.32, J2.32
~WR: J1.30, J2.30, U2.29 (~WE), U4.5 (I/O)

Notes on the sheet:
~{CARS1}
~{ROMS1}
~{MBEN}
~{CARS2}
RAMS2
RAMS1
To CPU board (original PROM socket)
~{ROMS2}
~{VIDS}

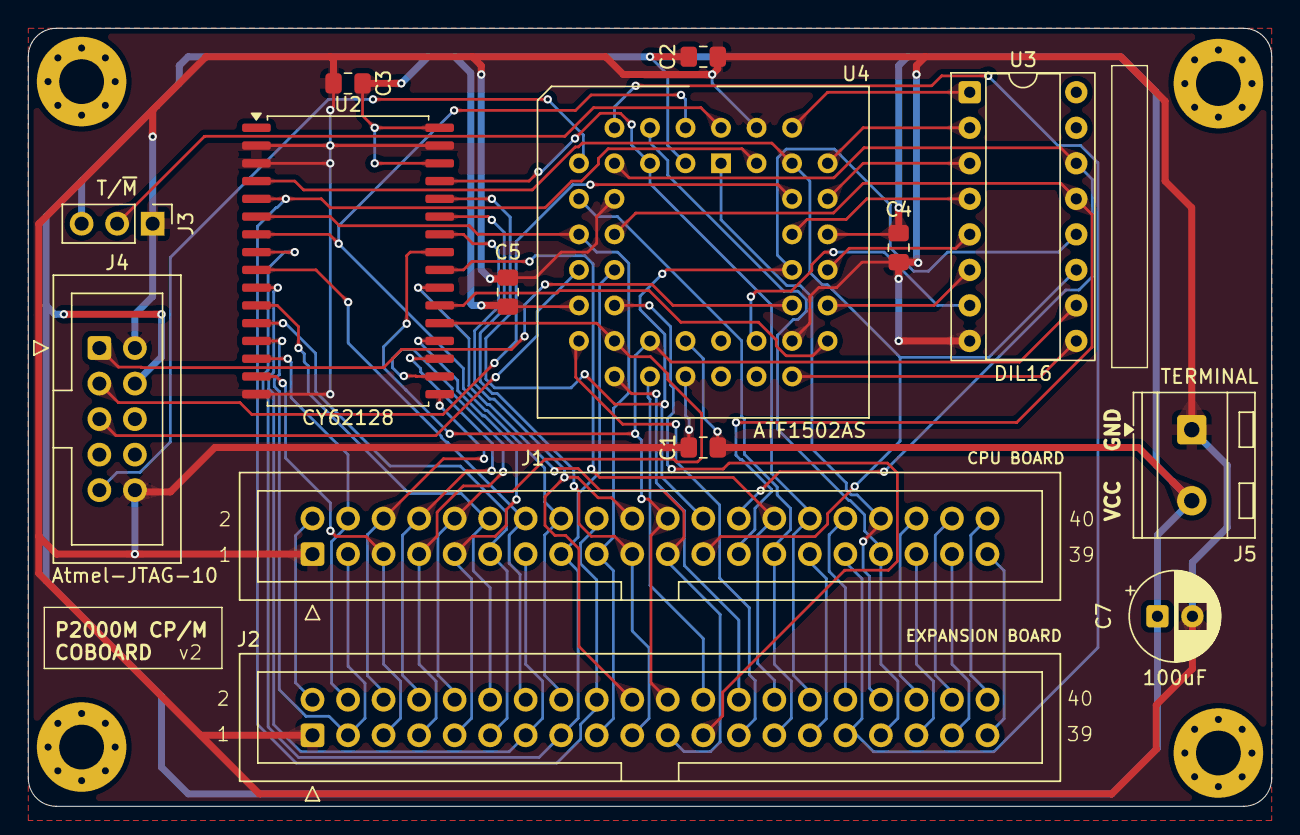
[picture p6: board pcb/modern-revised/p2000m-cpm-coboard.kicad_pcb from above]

Board: 2 copper layers, 88.9 x 55.6 mm, 18 parts (0 on the bottom side), 59 nets.

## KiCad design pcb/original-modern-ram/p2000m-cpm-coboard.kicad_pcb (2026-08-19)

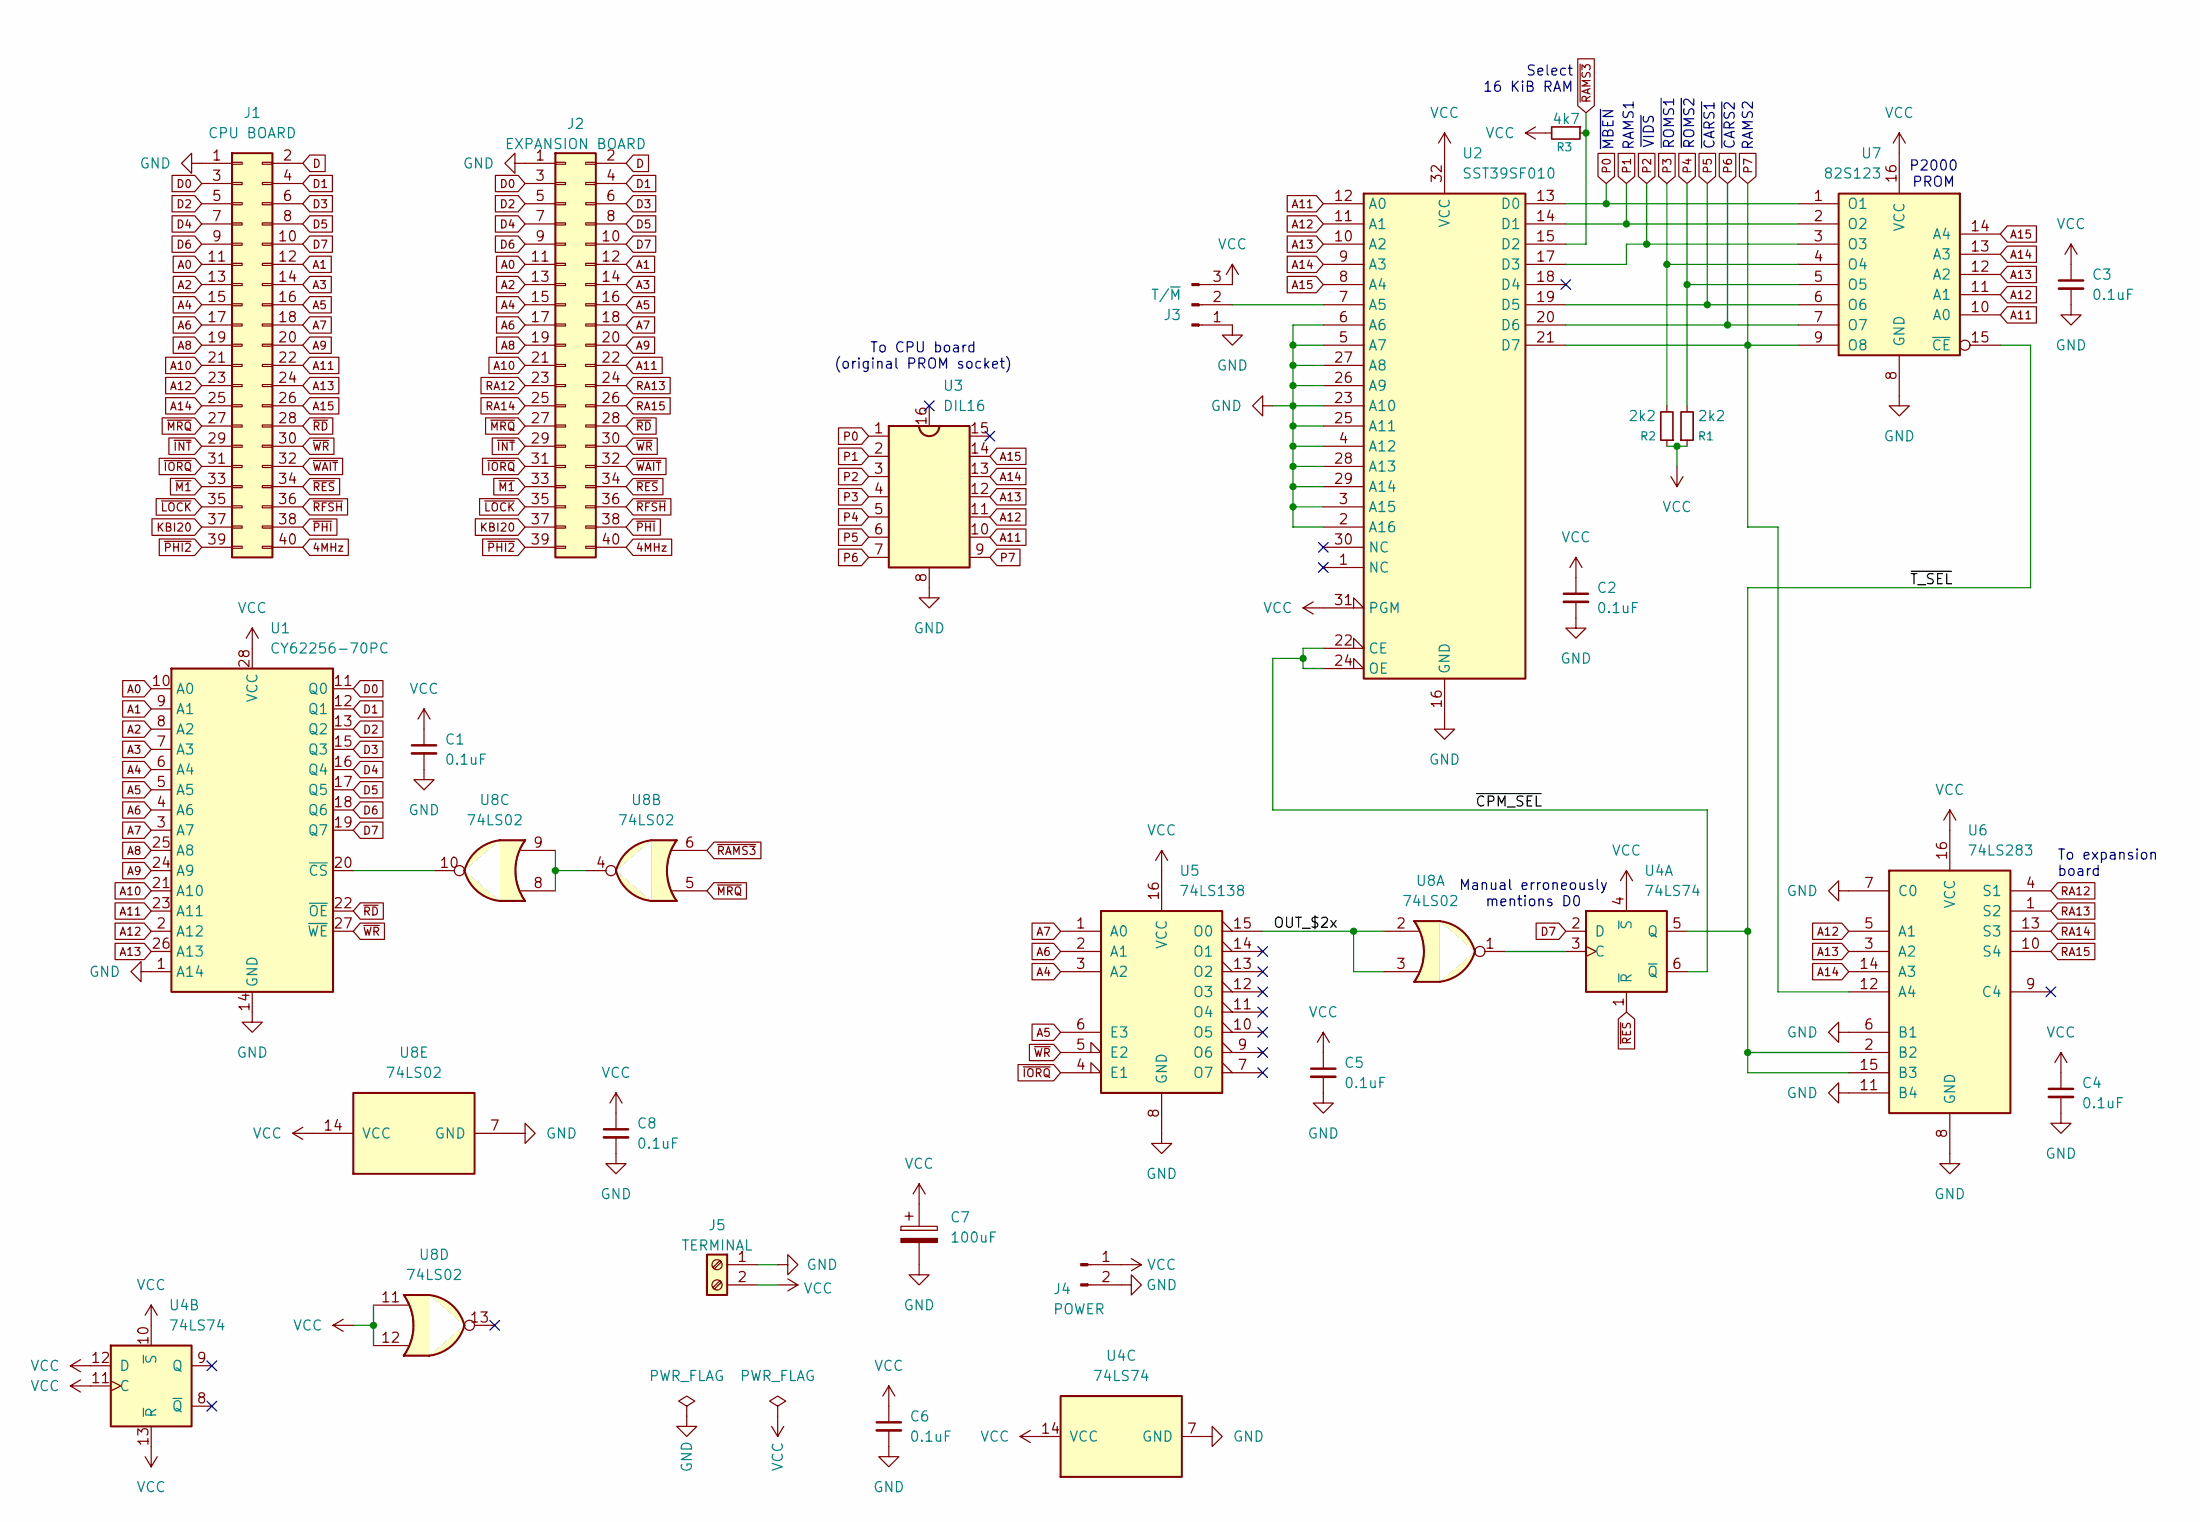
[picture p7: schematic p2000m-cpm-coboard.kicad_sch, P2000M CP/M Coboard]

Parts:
C1, C2, C3, C4, C5, C6, C8: 0.1uF; C_Disc_D5.0mm_W2.5mm_P5.00mm
C7: 100uF; CP_Radial_D6.3mm_P2.50mm
J1: CPU BOARD; IDC-Header_2x20_P2.54mm_Vertical
J2: EXPANSION BOARD; IDC-Header_2x20_P2.54mm_Vertical
J3: T/~{M}; PinHeader_1x03_P2.54mm_Vertical
J4: POWER; PinHeader_1x02_P2.54mm_Vertical
J5: TERMINAL; TerminalBlock_RND_205-00232_1x02_P5.08mm_Horizontal
R1, R2: 2k2; R_Axial_DIN0207_L6.3mm_D2.5mm_P7.62mm_Horizontal
R3: 4k7; R_Axial_DIN0207_L6.3mm_D2.5mm_P7.62mm_Horizontal
U1: CY62256-70PC; DIP-28_W15.24mm_Socket
U2: SST39SF010; PLCC-32_THT-Socket
U3: DIL16; DIP-16_W7.62mm_Socket
U4: 74LS74; DIP-14_W7.62mm_Socket
U5: 74LS138; DIP-16_W7.62mm_Socket
U6: 74LS283; DIP-16_W7.62mm_Socket
U7: 82S123; DIP-16_W7.62mm_Socket
U8: 74LS02; DIP-14_W7.62mm_Socket

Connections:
4MHz: J1.40, J2.40
/OUT_$2x: U5.15 (O0), U8.2, U8.3
/~CPM_SEL: U2.22 (CE), U2.24 (OE), U4.6 (~Q)
/~T_SEL: U4.5 (Q), U6.2 (B2), U6.15 (B3), U7.15 (~CE)
A0: J1.11, J2.11, U1.10 (A0)
A1: J1.12, J2.12, U1.9 (A1)
A2: J1.13, J2.13, U1.8 (A2)
A3: J1.14, J2.14, U1.7 (A3)
A4: J1.15, J2.15, U1.6 (A4), U5.3 (A2)
A5: J1.16, J2.16, U1.5 (A5), U5.6 (E3)
A6: J1.17, J2.17, U1.4 (A6), U5.2 (A1)
A7: J1.18, J2.18, U1.3 (A7), U5.1 (A0)
A8: J1.19, J2.19, U1.25 (A8)
A9: J1.20, J2.20, U1.24 (A9)
A10: J1.21, J2.21, U1.21 (A10)
A11: J1.22, J2.22, U1.23 (A11), U2.12 (A0), U3.10, U7.10 (A0)
A12: J1.23, U1.2 (A12), U2.11 (A1), U3.11, U6.5 (A1), U7.11 (A1)
A13: J1.24, U1.26 (A13), U2.10 (A2), U3.12, U6.3 (A2), U7.12 (A2)
A14: J1.25, U2.9 (A3), U3.13, U6.14 (A3), U7.13 (A3)
A15: J1.26, U2.8 (A4), U3.14, U7.14 (A4)
D: J1.2, J2.2
D0: J1.3, J2.3, U1.11 (Q0)
D1: J1.4, J2.4, U1.12 (Q1)
D2: J1.5, J2.5, U1.13 (Q2)
D3: J1.6, J2.6, U1.15 (Q3)
D4: J1.7, J2.7, U1.16 (Q4)
D5: J1.8, J2.8, U1.17 (Q5)
D6: J1.9, J2.9, U1.18 (Q6)
D7: J1.10, J2.10, U1.19 (Q7), U4.2 (D)
GND: C1.2, C2.2, C3.2, C4.2, C5.2, C6.2, C7.2, C8.2, J1.1, J2.1, J3.1, J4.2, J5.1, U1.1 (A14), U1.14 (GND), U2.2 (A16), U2.3 (A15), U2.4 (A12), U2.5 (A7), U2.6 (A6), U2.16 (GND), U2.23 (A10), U2.25 (A11), U2.26 (A9), U2.27 (A8), U2.28 (A13), U2.29 (A14), U3.8, U4.7 (GND), U5.8 (GND), U6.6 (B1), U6.7 (C0), U6.8 (GND), U6.11 (B4), U7.8 (GND), U8.7 (GND)
KBI20: J1.37, J2.37
unnamed: J3.2, U2.7 (A5)
unnamed: U1.20 (~CS), U8.10
unnamed: U4.3 (C), U8.1
unnamed: U8.4, U8.8, U8.9
P0: U2.13 (D0), U3.1, U7.1 (O1)
P1: U2.14 (D1), U3.2, U7.2 (O2)
P2: U2.17 (D3), U3.3, U7.3 (O3)
P3: R2.2, U3.4, U7.4 (O4)
P4: R1.2, U3.5, U7.5 (O5)
P5: U2.19 (D5), U3.6, U7.6 (O6)
P6: U2.20 (D6), U3.7, U7.7 (O7)
P7: U2.21 (D7), U3.9, U6.12 (A4), U7.9 (O8)
RA12: J2.23, U6.4 (S1)
RA13: J2.24, U6.1 (S2)
RA14: J2.25, U6.13 (S3)
RA15: J2.26, U6.10 (S4)
VCC: C1.1, C2.1, C3.1, C4.1, C5.1, C6.1, C7.1, C8.1, J3.3, J4.1, J5.2, R1.1, R2.1, R3.2, U1.28 (VCC), U2.31 (PGM), U2.32 (VCC), U4.4 (~S), U4.10 (~S), U4.11 (C), U4.12 (D), U4.13 (~R), U4.14 (VCC), U5.16 (VCC), U6.16 (VCC), U7.16 (VCC), U8.11, U8.12, U8.14 (VCC)
~INT: J1.29, J2.29
~IORQ: J1.31, J2.31, U5.4 (E1)
~LOCK: J1.35, J2.35
~M1: J1.33, J2.33
~MRQ: J1.27, J2.27, U8.5
~PHI2: J1.39, J2.39
~PHI: J1.38, J2.38
~RAMS3: R3.1, U2.15 (D2), U8.6
~RD: J1.28, J2.28, U1.22 (~OE)
~RES: J1.34, J2.34, U4.1 (~R)
~RFSH: J1.36, J2.36
~WAIT: J1.32, J2.32
~WR: J1.30, J2.30, U1.27 (~WE), U5.5 (E2)

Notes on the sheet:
~{ROMS1}
~{CARS2}
Manual erroneously mentions D0
P2000 PROM
To expansion board
Select 16 KiB RAM
~{MBEN}
RAMS1
~{ROMS2}
~{VIDS}
RAMS2
To CPU board (original PROM socket)
~{CARS1}

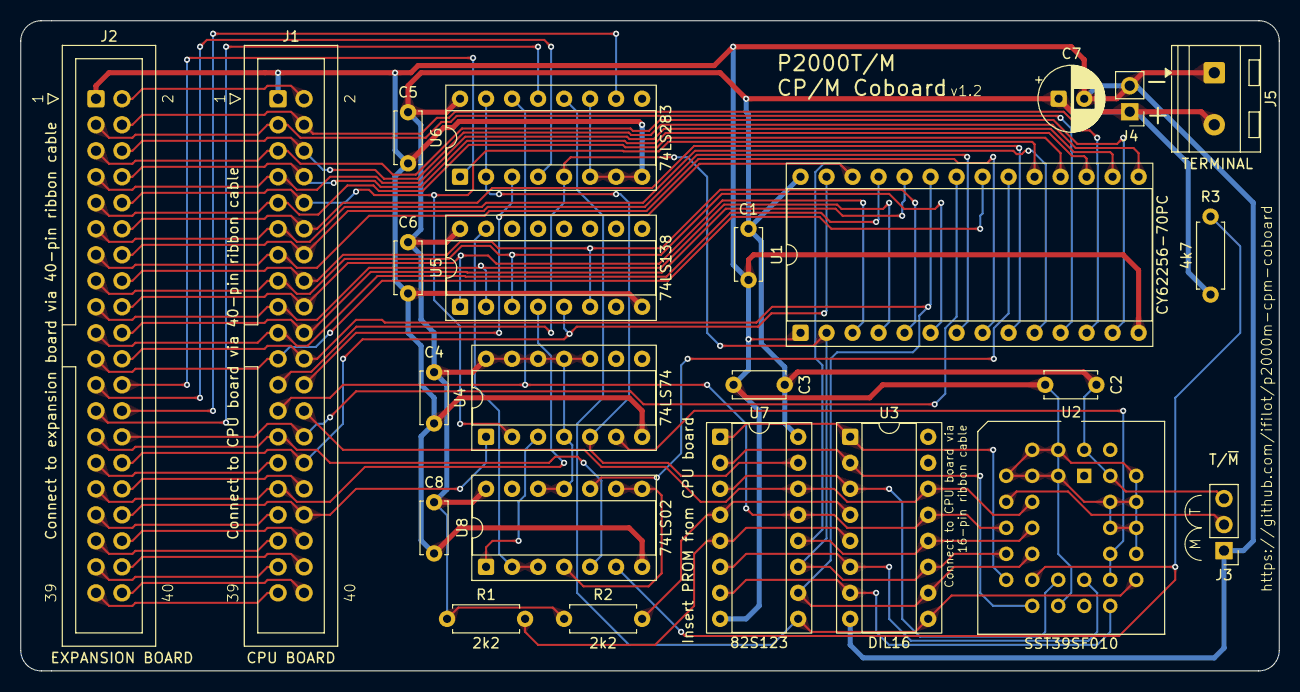
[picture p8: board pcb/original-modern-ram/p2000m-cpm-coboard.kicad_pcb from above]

Board: 2 copper layers, 122.9 x 63.5 mm, 24 parts (0 on the bottom side), 61 nets.

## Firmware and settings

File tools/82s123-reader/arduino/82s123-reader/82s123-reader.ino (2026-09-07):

// ====================================================================
// 82S123 ROM Reader - Arduino Leonardo
// --------------------------------------------------------------------
// Wiring summary:
//   ROM A0-A4  -> D2, D3, D4, D5, D6
//   ROM /CE    -> D7
//   ROM D0-D3  -> A3-A0 (PF4-PF7)
//   ROM D4-D7  -> D8-D11 (PB4-PB7)
// --------------------------------------------------------------------
// Serial command protocol (115200 baud, 8N1, newline-terminated ASCII
// commands). This firmware is driven by a host application (e.g. the
// companion Qt6 GUI) instead of auto-dumping on boot, so reads always
// happen on request and can be verified by the host.
//
//   PING   -> "PONG 82S123-READER v0.1.0"
//   READ   -> 32 lines "AA:DD" (address:data, hex), then "CHK:xx"
//             (XOR checksum of all 32 data bytes), then "OK"
//   other  -> "ERR UNKNOWN_CMD <cmd>"
// ====================================================================

const int ADDR_PINS[5] = {2, 3, 4, 5, 6};
const int CE_PIN = 7;
const int DATA_LOW_PINS[4] = {A3, A2, A1, A0};  // D0-D3
const int DATA_HIGH_PINS[4] = {8, 9, 10, 11};   // D4-D7

const char *FIRMWARE_ID = "82S123-READER";
const char *FIRMWARE_VERSION = "v0.1.1";

const uint8_t MAX_LINE_LENGTH = 64;
String inputLine;

void print_hex2(uint8_t v) {
  if (v < 16) Serial.print('0');
  Serial.print(v, HEX);
}

uint8_t read_byte(uint8_t addr) {
  // Output address bits
  for (int bit = 0; bit < 5; bit++) {
    digitalWrite(ADDR_PINS[bit], (addr >> bit) & 1);
  }

  // Enable chip
  digitalWrite(CE_PIN, LOW);
  delayMicroseconds(5); // allow ROM outputs to settle

  // Read data bits
  uint8_t value = 0;
  for (int bit = 0; bit < 4; bit++) {
    value |= (digitalRead(DATA_LOW_PINS[bit]) << bit);
    value |= (digitalRead(DATA_HIGH_PINS[bit]) << (bit + 4));
  }

  // Disable chip
  digitalWrite(CE_PIN, HIGH);

  return value;
}

void cmd_ping() {
  Serial.print(F("PONG "));
  Serial.print(FIRMWARE_ID);
  Serial.print(' ');
  Serial.println(FIRMWARE_VERSION);
}

void cmd_read() {
  uint8_t checksum = 0;

  for (uint16_t addr = 0; addr < 32; addr++) {
    uint8_t value = read_byte((uint8_t)addr);
    checksum ^= value;

    print_hex2((uint8_t)addr);
    Serial.print(':');
    print_hex2(value);
    Serial.print('\n');
  }

  Serial.print(F("CHK:"));
  print_hex2(checksum);
  Serial.print('\n');
  Serial.println(F("OK"));
}

void handle_command(String cmd) {
  cmd.trim();
  cmd.toUpperCase();
  if (cmd.length() == 0) return;

  if (cmd == "PING") {
    cmd_ping();
  } else if (cmd == "READ") {
    cmd_read();
  } else {
    Serial.print(F("ERR UNKNOWN_CMD "));
    Serial.println(cmd);
  }
}

void setup() {
  Serial.begin(115200);
  // Deliberately not "while (!Serial);" here: that gate waits for the host
  // to assert DTR, which the Arduino Serial Monitor and avrdude do
  // automatically but generic serial libraries (e.g. Qt's QSerialPort, as
  // used by the companion GUI) do not do by default. Native-USB boards like
  // the Leonardo can transmit/receive over CDC as soon as they're
  // enumerated regardless of that flag, so skipping the wait keeps the
  // board responsive to any host without relying on DTR behavior.

  // A0-A3 double as the ATmega32U4's on-chip JTAG interface (TDI/TDO/TMS/TCK
  // on PF7-PF4). If the JTAGEN fuse is left programmed, JTAG claims those
  // four pins at every reset until software disables it, which can prevent
  // ordinary GPIO functions -- including pinMode(..., INPUT_PULLUP) below --
  // from reaching the physical pin (A0/TDI is affected; TCK/TMS/TDO get an
  // automatic JTAG-internal pull-up so they read fine regardless). This
  // project never uses JTAG, so disable it unconditionally; per the
  // datasheet, disabling requires writing JTD twice within four cycles.
  noInterrupts();
  MCUCR |= (1 << JTD);
  MCUCR |= (1 << JTD);
  interrupts();

  // Address + CE as outputs
  for (int i = 0; i < 5; i++) {
    pinMode(ADDR_PINS[i], OUTPUT);
    digitalWrite(ADDR_PINS[i], LOW);
  }
  pinMode(CE_PIN, OUTPUT);
  digitalWrite(CE_PIN, HIGH); // /CE inactive

  // Data as inputs
  for (int i = 0; i < 4; i++) {
    pinMode(DATA_LOW_PINS[i], INPUT_PULLUP);
    pinMode(DATA_HIGH_PINS[i], INPUT_PULLUP);
  }

  inputLine.reserve(MAX_LINE_LENGTH);
}

void loop() {
  while (Serial.available() > 0) {
    char c = (char)Serial.read();

    if (c == '\n' || c == '\r') {
      if (inputLine.length() > 0) {
        handle_command(inputLine);
        inputLine = "";
      }
    } else {
      inputLine += c;
      // Guard against a runaway/garbled line filling up memory.
      if (inputLine.length() >= MAX_LINE_LENGTH) {
        inputLine = "";
      }
    }
  }
}

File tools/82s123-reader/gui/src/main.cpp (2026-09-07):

#include <QApplication>
#include <QIcon>

#include "mainwindow.h"

int main(int argc, char *argv[])
{
    QApplication app(argc, argv);
    QApplication::setOrganizationName(QStringLiteral("82S123Reader"));
    QApplication::setApplicationName(QStringLiteral("82S123 ROM Reader"));
    QApplication::setApplicationVersion(QStringLiteral("0.1.0"));

    // Multi-resolution app icon: title bar, taskbar/dock, Alt-Tab, etc.
    // (the .exe's own icon on Windows comes from resources/app.ico via the
    // generated .rc resource script, embedded at link time.)
    QIcon appIcon;
    appIcon.addFile(QStringLiteral(":/icons/app-16.png"));
    appIcon.addFile(QStringLiteral(":/icons/app-32.png"));
    appIcon.addFile(QStringLiteral(":/icons/app-48.png"));
    appIcon.addFile(QStringLiteral(":/icons/app-128.png"));
    appIcon.addFile(QStringLiteral(":/icons/app-256.png"));
    QApplication::setWindowIcon(appIcon);

    MainWindow window;
    window.show();

    return QApplication::exec();
}

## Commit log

2026-08-09 Initial commit PCB
    [p2000m-cpm-coboard.kicad_pcb, p2000m-cpm-coboard.kicad_sch]
2026-08-09 Initial commit schematic
    [p2000m-cpm-coboard.kicad_pcb, p2000m-cpm-coboard.kicad_sch]
2026-08-09 Adding Python script to analyze wiring and add TODO with current fixes to make
    [p2000m-cpm-coboard.kicad_pcb]
2026-08-10 Initial commit of PCB layout and fixing some bugs
    [p2000m-cpm-coboard.dsn, p2000m-cpm-coboard.kicad_pcb, p2000m-cpm-coboard.kicad_sch]
2026-08-10 Polishing PCB
    [p2000m-cpm-coboard.kicad_pcb, p2000m-cpm-coboard.kicad_sch]
2026-08-11 Adding pull-up resistor to RAMS3/ and updating mappings
    [p2000m-cpm-coboard.kicad_pcb, p2000m-cpm-coboard.kicad_sch]
2026-08-18 Replacing DIP for PLCC32 for SST39SF010
    [connector-B_Cu.gbr, connector-B_Mask.gbr, connector-B_Paste.gbr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]
2026-08-18 Adding 82S123 contents
    [p2000m-cpm-coboard.kicad_pcb, p2000m-cpm-coboard.kicad_sch]
2026-08-19 Rerouting by hand
    [p2000m-cpm-coboard-B_Cu.gbr, p2000m-cpm-coboard-B_Mask.gbr, p2000m-cpm-coboard-B_Paste.gbr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]
2026-08-19 Fixing bug in wiring
    [p2000m-cpm-coboard-B_Cu.gbr, p2000m-cpm-coboard-B_Mask.gbr, p2000m-cpm-coboard-B_Paste.gbr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]
2026-08-22 Creating board based on CPLD chip
    [p2000m-cpm-coboard-B_Cu.gbr, p2000m-cpm-coboard-B_Mask.gbr, p2000m-cpm-coboard-B_Paste.gbr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]
2026-08-22 End of work commit
    [p2000m-cpm-coboard.kicad_pcb]
2026-09-07 Adding default PROM, fixing labeling, adding reader firmware
    [p2000m-cpm-coboard.kicad_pcb]
